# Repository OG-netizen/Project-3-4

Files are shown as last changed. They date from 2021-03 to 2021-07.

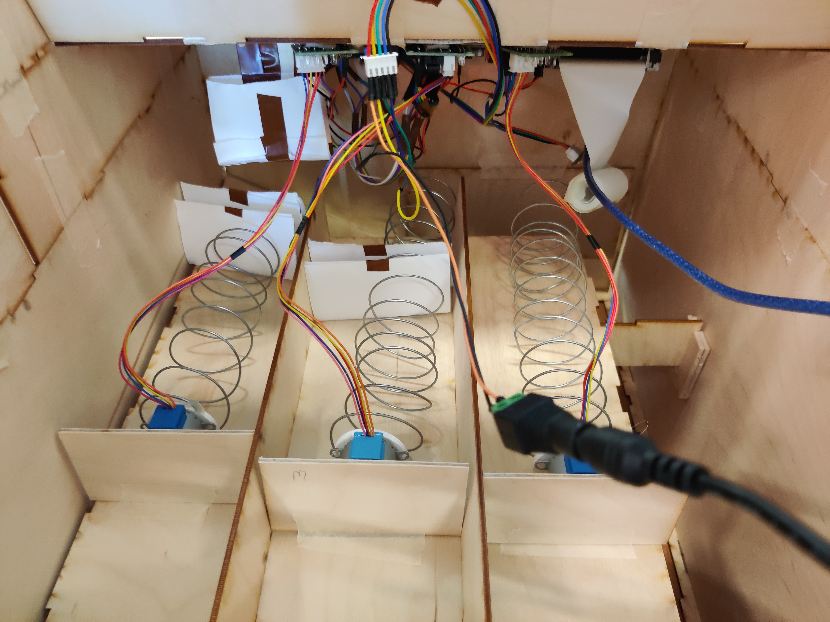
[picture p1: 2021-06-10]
Documenten/Atm binnenkant.jpg

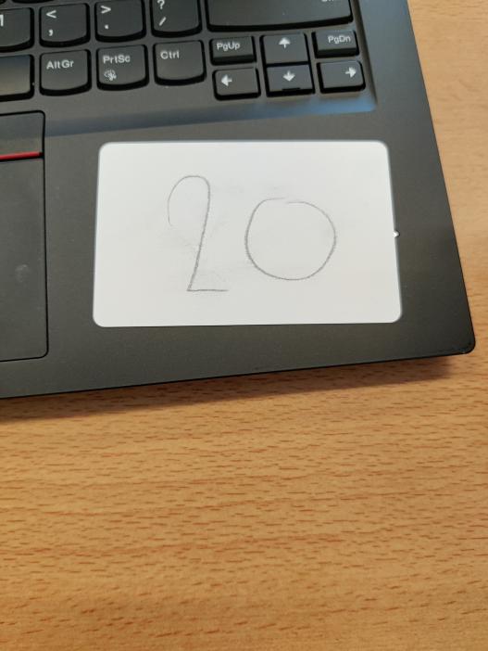
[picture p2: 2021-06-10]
Documenten/biljet.jpg

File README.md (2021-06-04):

# Project-3/4

Voor dit project moesten we een ATM 🏧 en een banksysteem 💻 bouwen. 



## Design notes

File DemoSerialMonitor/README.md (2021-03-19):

Dit is de serial monitor communicatie tussen java en arduino.

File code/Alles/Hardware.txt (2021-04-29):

3 Motoren 	|| 4*3 = 12 pins || 1*3 = 3 5v || 1*3 = 3 gnd
1 Bonprinter 	|| 3 pins || 1 gnd ||stekker 
1 RFID 		|| 5 pins || 1 3v || 1 gnd
1 Keypad	|| 8 pins
8 Buttons	||

totaal 		|| 28 pins || 1 3v || 3 5v || 5 gnd || 1 stekker

Pins used:
Motoren: 12
23, 25, 26, 27, 28, 29, 30, 32, 34, 36, 38, 40

Bonprinter: 2
37, 39

Keypad: 8
42, 43, 44, 45, 46, 47, 48, 49

RFID: 5
5, 50, 51, 52, 53

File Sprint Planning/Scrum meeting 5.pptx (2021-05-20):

## PO Meeting

## Sprint review

- Land voor onze landserver
- Flowchart aangepast
- Sketch gemaakt voor lasercutting

## Nieuwe flowchart

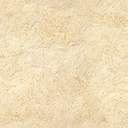
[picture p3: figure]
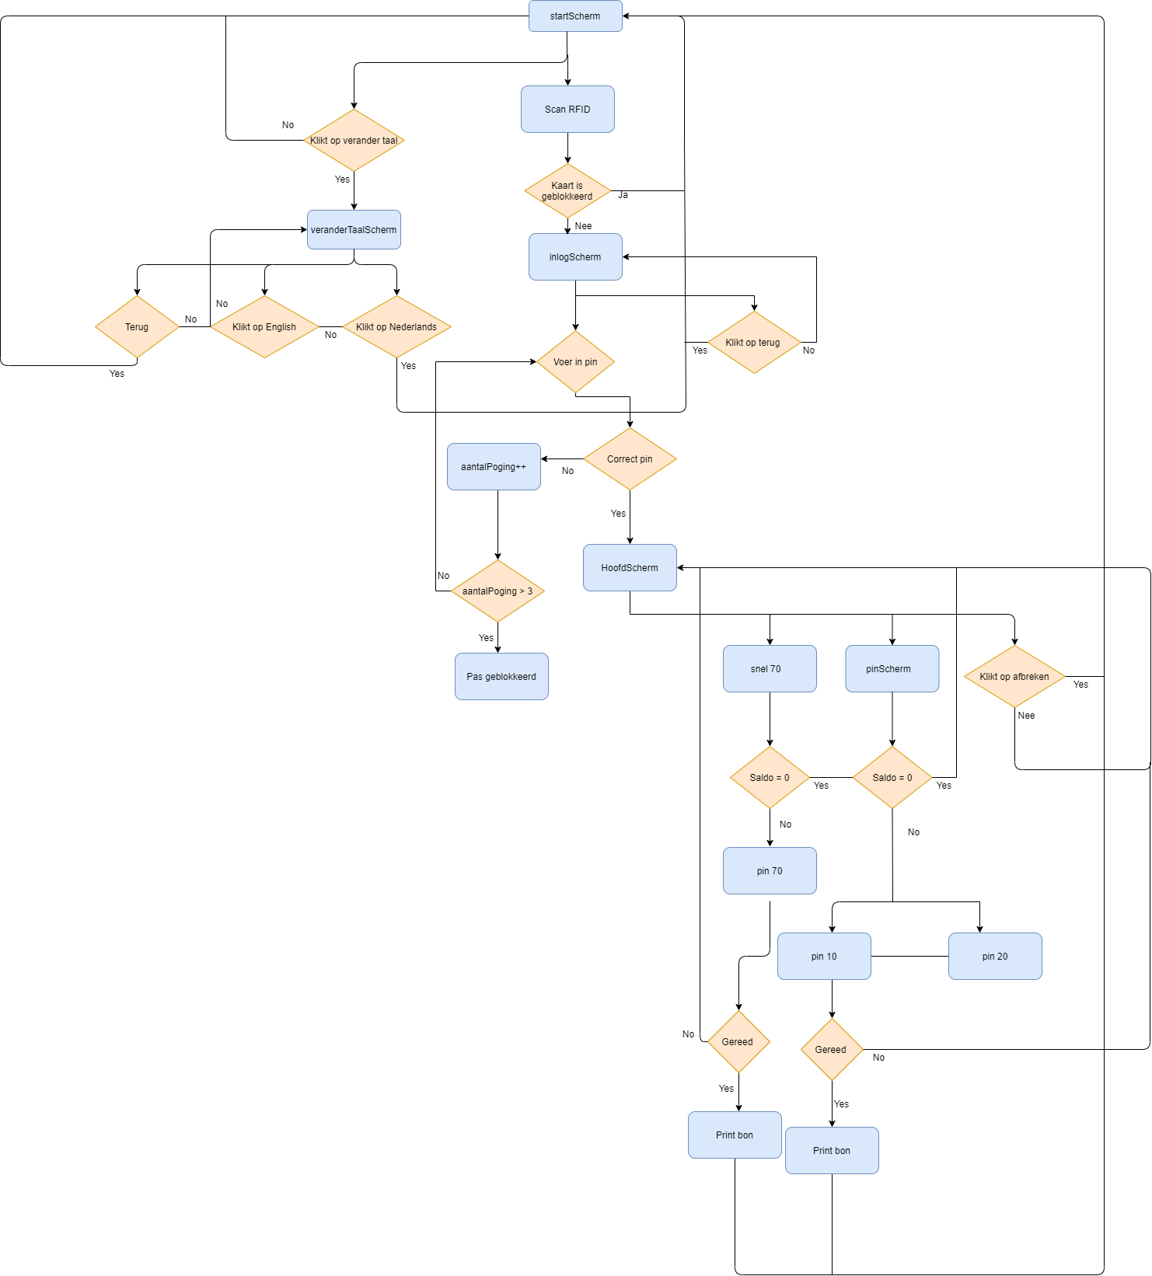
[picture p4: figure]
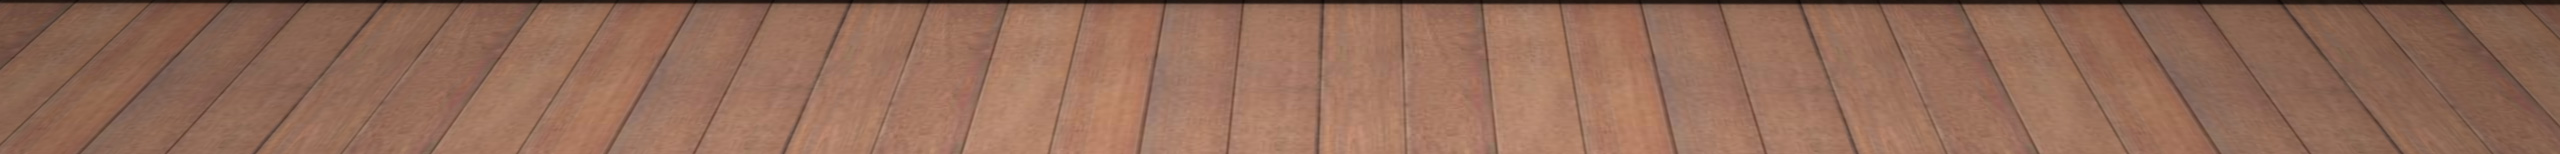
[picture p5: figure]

## Land

- Niger
- Country Code : ISO 3166 alpha-2 NE
- IP Adress landserver: 145.24.222.250
- Iban : NI42 FATM 8765 4321
- Port 22

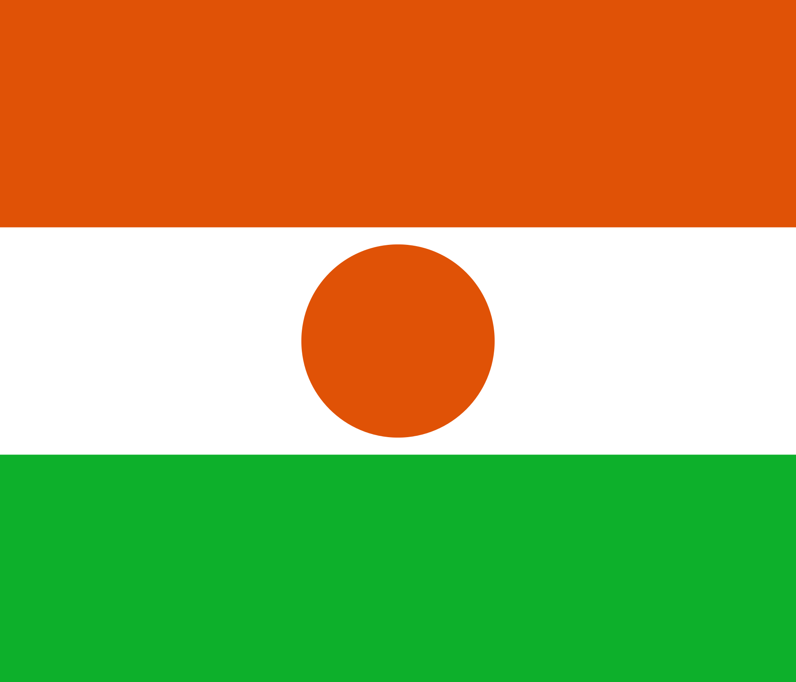
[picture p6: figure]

## Lasercutting sketch

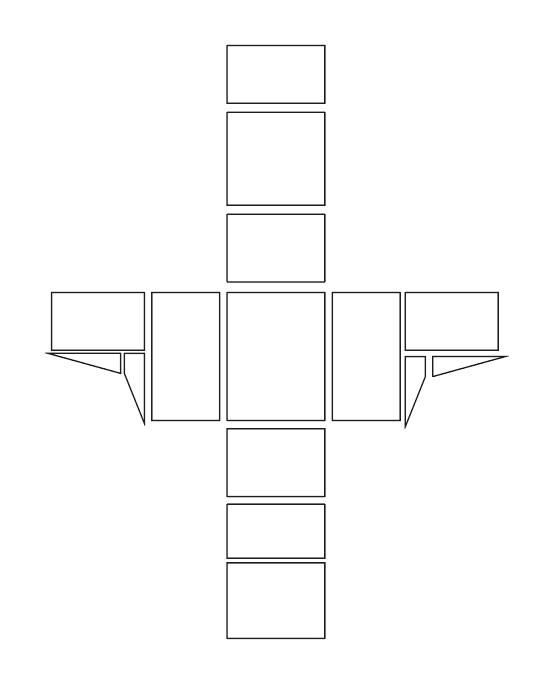
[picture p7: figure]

## demonstratie

- Inloggen
- Pinnen
- Stepper motoren
- Bon printer

## OUDE Presentatie Sprint Backlog

Features | Wil ik | Als gebruiker | Waarom | Taken | Moeilijkheids-graad | Acceptance criteria
7 | Prototype maken van de ATM | De werknemer | Zodat de werknemer alle hardware componenten kunnen testen | Ontwerp bovenkant lasersnijden met afmetingen | 10 | Ontwerp bovenkant moet gaten bevatten voor 8 knoppen, Pin ingang, Bon uitgang, numpad, Laptop scherm stand.
| | | | Ontwerp onderkant laser cutten met afmetingen | | Ontwerp onderkant moet gaten bevatten voor de biljetten dispenser.
| | | | Dispenser ontwerp laser cutten met afmetingen | | Dispenser moet 3 dispenser bakken bevatten om de biljetten uit te werpen.

## nieuwe Presentatie Sprint Backlog

Features | Wil ik | Als gebruiker | Waarom | Taken | Moeilijkheids-graad | Acceptance criteria
8 | Pinnen in elke landen | De klanten | Het zou fijn zijn als klanten kan pinnen in andere landen. Dan weet de klant dat hij/zij met rust kan geld opnemen in andere landen. | Programmeren van een REST API voor het interactie met de landserver | 7 | Ontwerp bovenkant moet gaten bevatten voor 8 knoppen, Pin ingang, Bon uitgang, numpad, Laptop scherm stand.
| | | | Setup onze landserver | 6 | Ontwerp onderkant moet gaten bevatten voor de biljetten dispenser.
| | | | Landserver kan communiceren met de NOOB server | 7 | Dispenser moet 3 dispenser bakken bevatten om de biljetten uit te werpen.

## Retrospective

  - Wat kan er beter?

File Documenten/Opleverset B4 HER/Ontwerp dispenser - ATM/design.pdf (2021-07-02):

390 mm

510 mm

Grootte ribbels en dikte plank is 3mm | Dispenser

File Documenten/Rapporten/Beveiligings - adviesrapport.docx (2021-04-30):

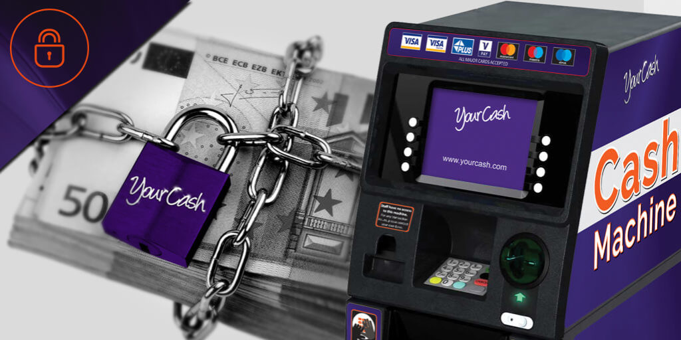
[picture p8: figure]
Beveilig je geldautomaat, beveilig je klanten

Beveiligings- adviesrapport Project 3/4 | Namen - Bryan Chung (0990458) - Jia-jie Yeh (0992427) - Jurgen van den Berg (1000875) - Wouter van Huut (1018984) Groep :B4 / Klas :TI1B Inleverdatum 30-04-2021 Versie 1

# Hst 1. Beveiliging rapport

## 1.1 Data Flow Diagram (DFD)

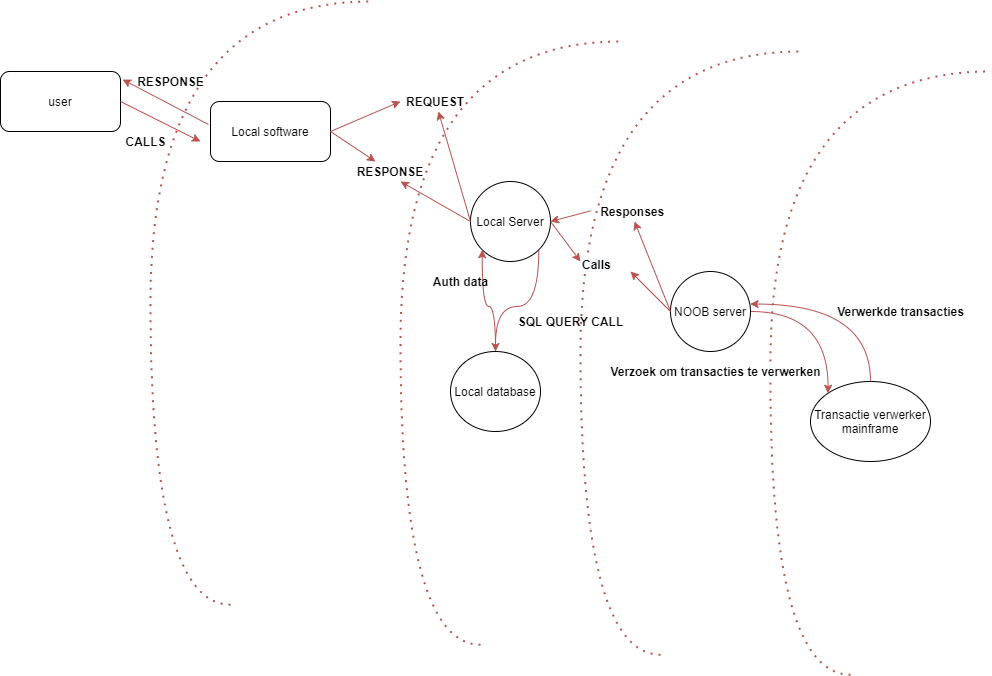
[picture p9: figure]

## 1.2 Risicoanalyse

| Soorten risico aanvallen | Uitvoering
1 | Rogue keyboard access | Dit is een fysiek toetsenbord koppelen aan een pinautomaat en vervolgens een stukje code of een SQL – injectie executeren. De aanvaller kan de pinautomaat dan controleren.
2 | Skimming | Met deze methode dupliceer je de gegevens van een pinpas. Dit gebeurd door een replica te maken van een pinautomaat en dat plaatsen ze aanvallers op het pin sectie.
3 | Keylogging | Dit is het zelfde geval van skimming, maar dan voor de gebruiker zijn pincode. Er wordt dan een replica keypad over het standaard pin keypad gelegd, waardoor de gebruiker zijn pincode wordt gestolen.
4 | Dataverbinding | Als er iemand tussen de dataverbinding van het systeem komt, dan is het systeem is niet versleuteld. Hierdoor zijn de onderdelen bijvoorbeeld; de informatie van de keypad en de gui zeer gevoelig.
5 | SQL | De gui moet beveiligd worden voor aanvallen, zoals SQL-injectie. Hierdoor krijgt de aanvaller gebruik tot je data in je database. Dit kan vernietigd of gestolen worden.
6 | Brute force | De aanvaller kan ook via brute force aanvallen op meerdere onderdelen van het systeem. Hierbij kunnen de data zoals; pincodes en wachtwoorden van de gebruiker te verkrijgen.

## 1.3 Maatregelen

| Soorten risico aanvallen | Oplossingen
1 | Rogue keyboard access | Dit is een van de makkelijkste aanvalssoort op de ATM, waardoor het ook gelijk makkelijk te detecteren is. Hierdoor kan je als een nieuw apparaat wordt toegevoegd dan wordt het ATM stop gezet. Je kan ook speciale karakters accepteren.
2 | Skimming | Dit kan je oplossen om door een elektromagnetische puls. Dit geeft een korte schok aan de skimmer. De schok verstoort of beschadigd de skimmer.
3 | Keylogging | De aanvaller is moeilijk te detecteren, want tegenwoordig niet altijd een keypad replica gebruikt, maar ook een USB-stick. Eerst was de oplossing voelen aan de toetsenbord en kijken of het nep is. Dit is het zelfde geval bij het gebruik van de rogue keyboard.
4 | Dataverbinding | Dit valt op te lossen om beveiliging te maken door middel van SHA-3^15 hash of encryptie. Hierdoor krijgt de aanvaller onleesbare data.
5 | SQL | Deze aanval kan je voorkomen om de input validatie te gebruiken.
6 | Brute force | Om het systeem te beschermen tegen DDoS aanvallen van de aanvaller kan je bijvoorbeeld een Anti DDoS systeem gebruiken. In Nederland is een bekende zogenaamd NaWas. Er is ook een Nationale Anti-DDoS coalitie.

## 1.4 Attack tree

Om een helder beeld te krijgen van een beveiligingssysteem wordt er een attack tree gemaakt. Deze attack tree geeft een beeld over de situaties van de risico aanvallen op het systeem en hoe het systeem op reageert.

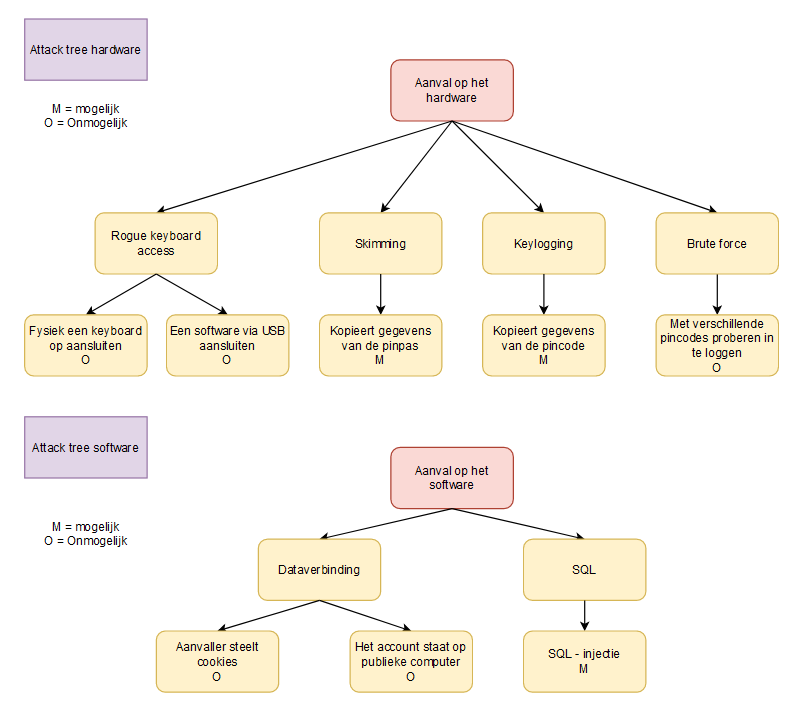
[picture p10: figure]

## Literatuurlijst

# Beveiligingsbronnen

1. https://www.kaspersky.com/blog/atm-attacks-2/15160/

https://jarnobaselier.nl/rogue-access-point-easy-wifi-hacking/

2. https://www.lookingglasscyber.com/blog/atm-hacking-you-dont-have-to-pay-to-play/

https://www.tpsworldwide.com/atm-skimming-preventing-bank-card-hacks/

https://mens-en-samenleving.infonu.nl/diversen/22626-hoe-skimmers-skimmen.html

3. https://www.pandasecurity.com/en/mediacenter/security/keyloggers-be-careful-what-you-type/

https://ecobank.com/personal-banking/security-centre/scams/keyloggers

https://www.malwarebytes.com/keylogger/

4. https://www.vpngids.nl/veilig-internet/surfen/wat-is-encryptie/
5. https://kinsta.com/nl/blog/sql-injecties/

https://cheatsheetseries.owasp.org/cheatsheets/SQL_Injection_Prevention_Cheat_Sheet.html

6. https://www.ncsc.nl/onderwerpen/ddos/het-nederlandse-anti-ddos-initiatief

https://www.nbip.nl/nawas/

# Hst 2. Advies rapport

## 2.1 onderzoeksvragen

- Is het ontwerp compleet, of mist het nog informatie?

Nee, het mist geen informatie en ziet er compleet uit. Het bevat alle standpunten en bij de literatuurlijst zijn alle belangrijke bronnen vermeld en door een website link verbonden.

- Kan er iets kapot gaan en verbeterd worden?

Ja, de dispenser uitgang kan ingebroken worden. Maar door een verbetering is het bedekt met een plaat, waardoor de aanvaller niet meer in kan komen.

- Zie je nog blinden vlekken die de peergroep gemist heeft?

Nee, we konden geen open plekken vinden. Waarbij aanvallen mogelijk zijn op de pinautomaat.

- Zijn de maatregelingen sterk genoeg?

Ja, de maatregelingen bedekken grotendeels de belangrijke zwakke punten van de bank. Zelfs heeft de peercoach groep meer dan 1 maatregelingen kunnen vinden voor 1 risico.

- Zijn de informatiebronnen uitgebreid genoeg?

De literatuurlijst is goed uitgebreid en verwerkt de standpunten van de bronnen die gebruikt zijn. Dit geeft een goed zicht waar het informatie vandaan komt.

- Ziet de attack tree van de peergroep goed uit?

De attack tree van de peergroep is ook in 2 delen verdeeld. In een hardware -en software gedeelte. Het hardware gedeelte is verdeeld hoe het fysiek ingebroken wordt, hoe moeilijk de hardware componenten betast worden en hoe de bank bescherming van de gelddispenser. Het software gedeelte is verdeeld in database hacken, datastroom onderscheppen, de GUI en pinpas stelen. Hier worden de moeilijkheidsgraden van de aanvallen gemankeerd met een ‘P van possible’ en ‘I van impossible’. Dit zorgt ervoor een gedetailleerde overzicht over de aanvallen op de bank.

- Is de DFD compleet?

Alle standpunten van de bank zijn er in verwerkt. De gebruiker heeft dan een laag voor het invoeren van zijn data dus de pincode, balans en card ID. Dit wordt dan verstuurd naar de volgende laag en dat is de ATM laag. Hier wordt de data van de gebruiker verstuurd naar de landelijke server. Dit wordt dan vergeleken met de banken die er allemaal verbonden zijn aan de landelijke server via een Iban id. Anders gaat het via de Noob server als het uit een andere land komt. Hier wordt dan de data terug gestuurd.

## 2.2 beveiligingsadvies

In het geheel is het beveiligingsrapport goed bedekt. De zwakke punten waar de bank overvallen kan worden zijn goed bedekt met maatregelen die het aanval proef maakt. Voor de rest ziet het er goed uit. De feedback zal ervoor zorgen dat de beveiligingsrapport verbeterd wordt. De bronnen zijn duidelijk met goeie standpunten ernaast en de attack tree/DFD geven een goed geheel over het ontwerp.

## 2.3 Advies landbank

- De communicatie tussen de banken wordt gedaan door een landelijke server op te zetten. Alle banken met de zelfde land verbinden hier dan aan. Als een persoon met een bankpas wilt gaan pinnen van een bank in het zelfde land dan is dit mogelijk.

Als de comminactieprotocol wordt er met een GET en POST request gewerkt. Deze request zijn dan onderdeel van een communicatie via HTTP verbinding. Hiermee wordt het veiliger gemaakt en gebruikt gemaakt van SSL. Dit protocol wordt dan HTTPS.

Dus wat ons peergroep down is een landelijke communicatie op te stellen en helpen opstellen met andere peergroepen. Hiermee worden de beveiliging van de verbinding tussen de pinautomaten, landelijke server en databases gemaakt. Door het besluit van de communicatie tussen banken in ons land hebben we een het onderwerp gelijk verdeeld met elkaar. Iedereen heeft dan evenveel te doen.

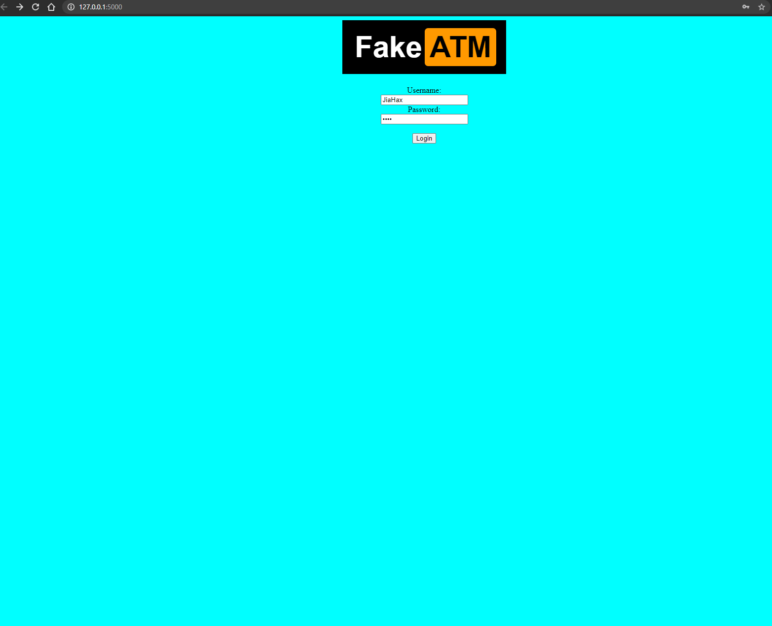
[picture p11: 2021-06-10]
Documenten/design.png

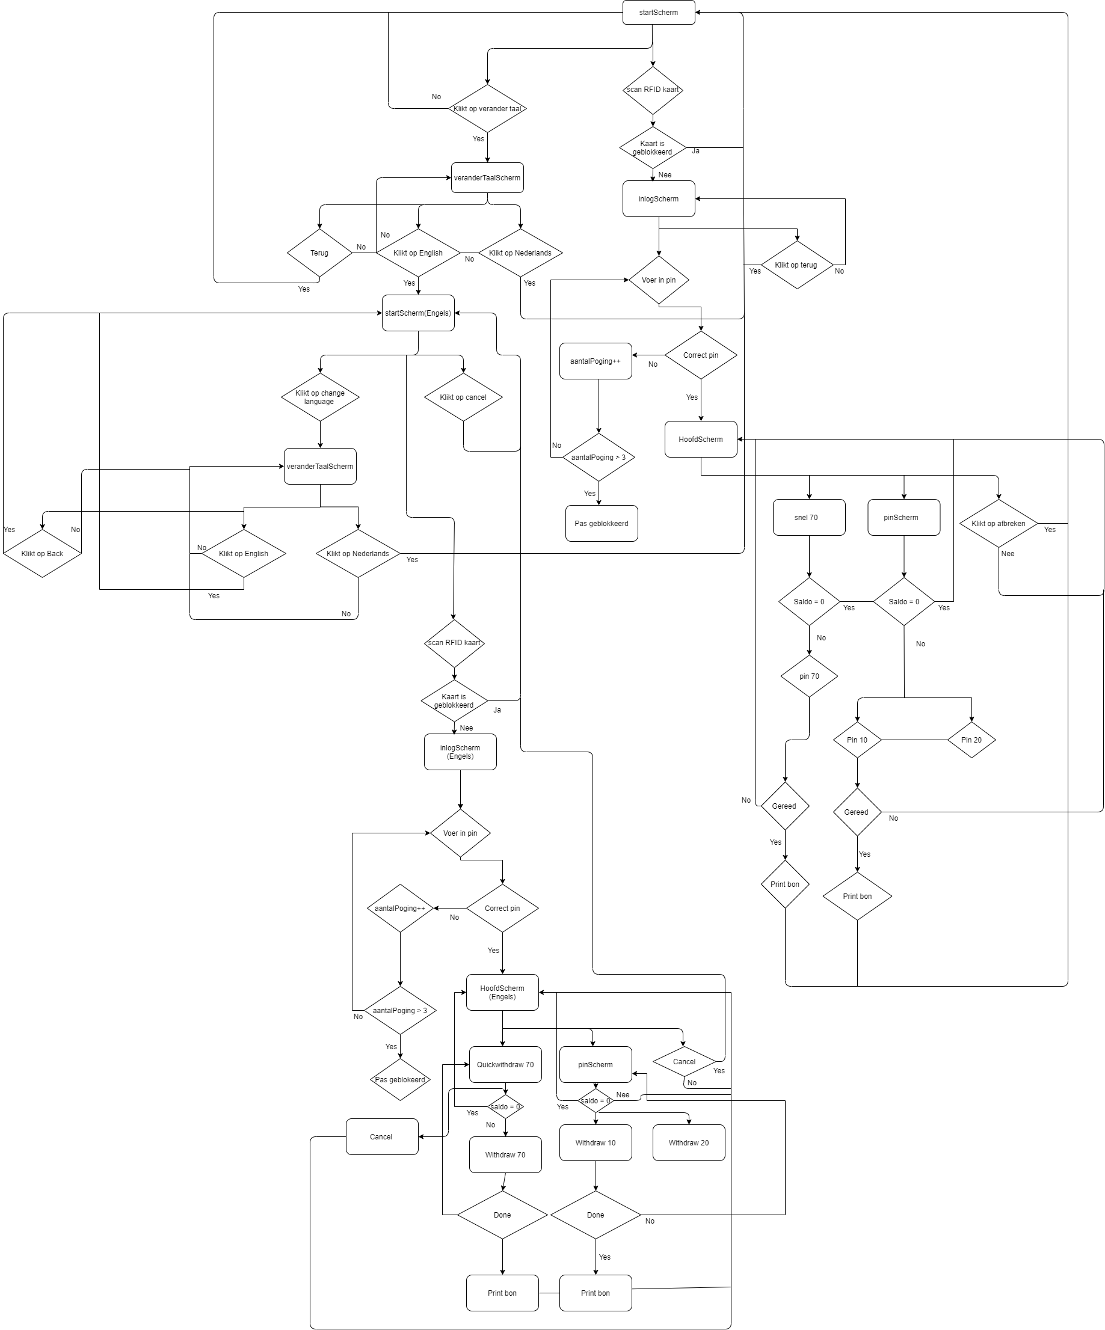
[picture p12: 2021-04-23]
Documenten/TweedeIteratieFlowChartGUI.png

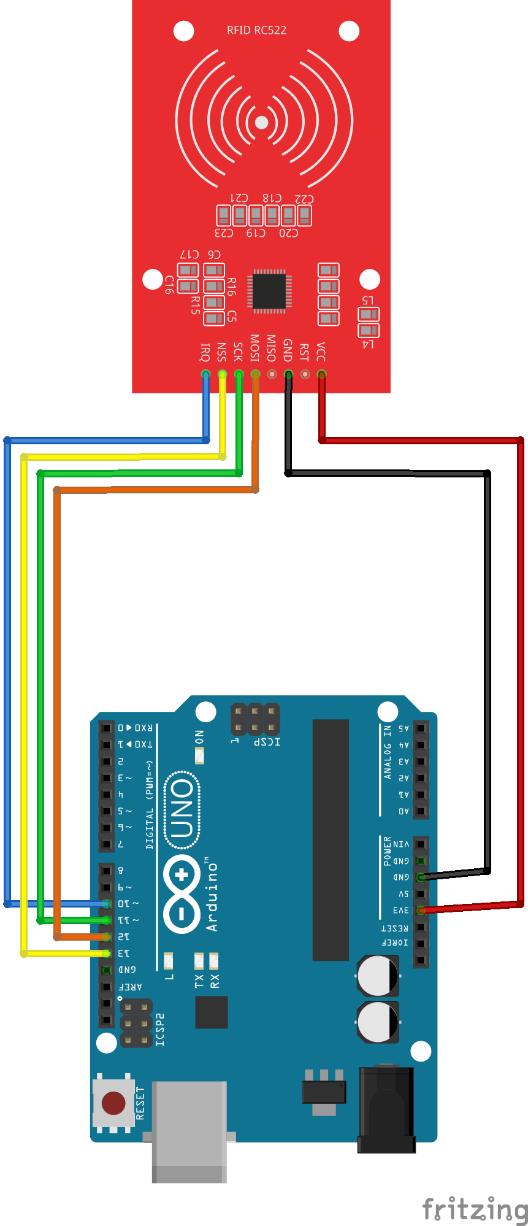
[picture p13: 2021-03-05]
code/Alles/Losse onderdelen/RFID/RFID_bb.png

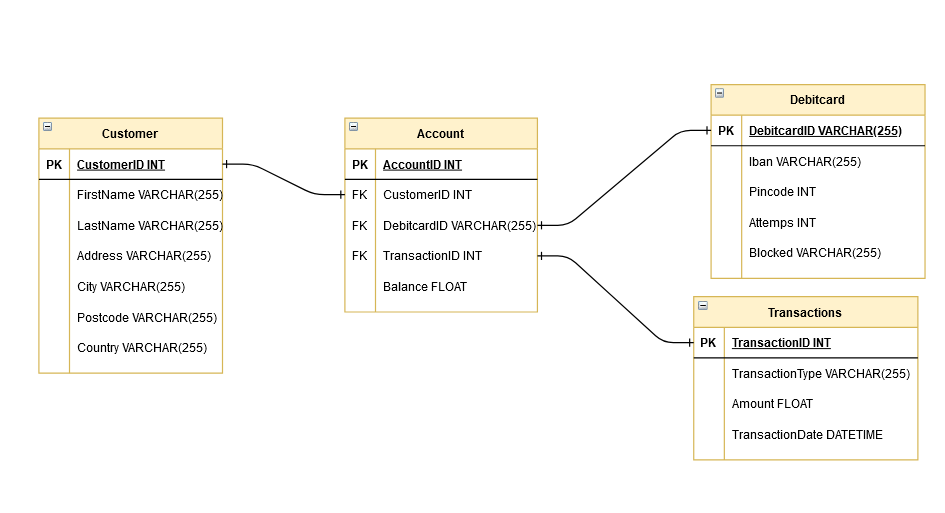
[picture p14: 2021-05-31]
Documenten/Database ontwerp/database ontwerp 4.png

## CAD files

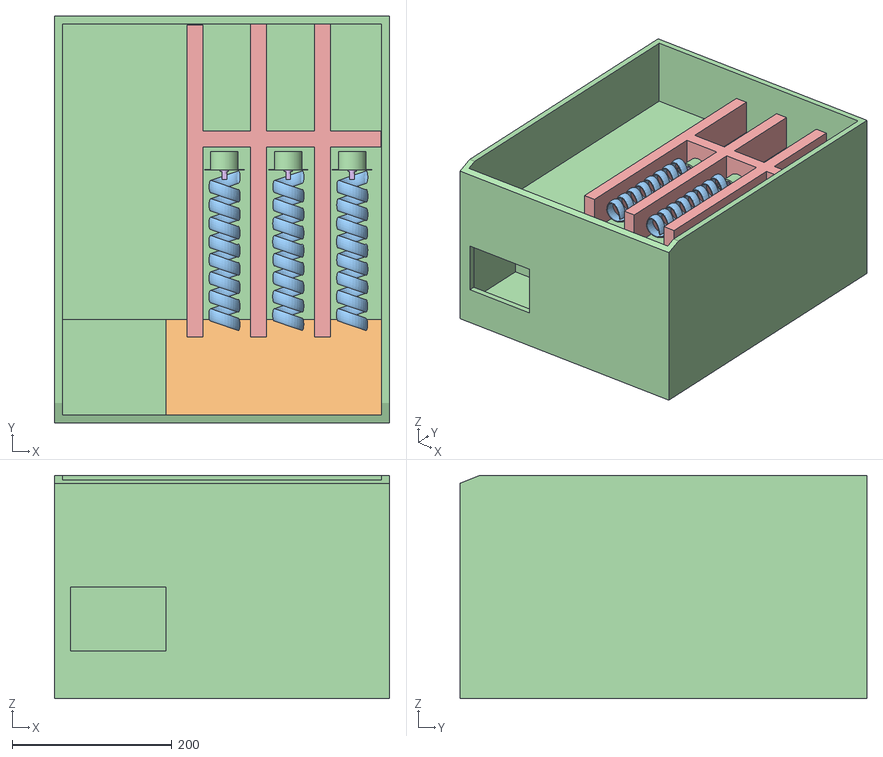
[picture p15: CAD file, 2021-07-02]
Documenten/Opleverset B4 HER/Ontwerp dispenser - ATM/FakeATM-dispenser.obj
420.0 x 510.0 x 280.0

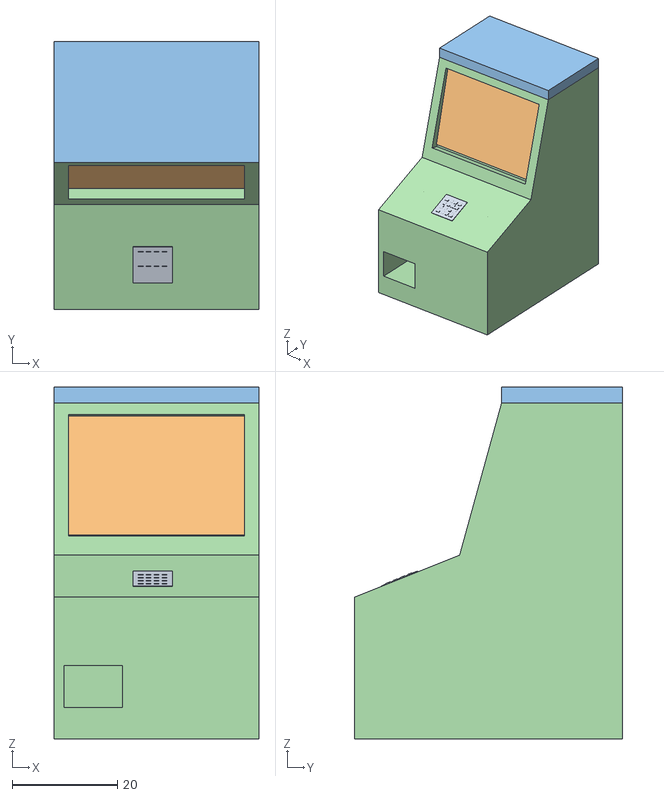
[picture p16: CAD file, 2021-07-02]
Documenten/Opleverset B4 HER/Ontwerp dispenser - ATM/FakeATM.obj
39.0 x 51.0 x 67.0

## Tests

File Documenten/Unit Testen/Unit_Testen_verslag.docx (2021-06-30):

Unit testen

Project 3/4

Groep: Bryan Chung (0990458), Jia-Jie-Yeh (0992427), Jurgen van den Berg (1000875),Wouter van Huut (1018984)

API

Eerste test

Test: Gaat de API de juiste response geven wanneer ze requests krijgt van de landserver. We willen ook weten bij edge case (extreem probleem) of het werkt.

Criteria:

De api moet kunnen de juiste response geven bij verschillende omstandigheden. Bij een edge case moet onze api door moeten draaien. Als er 0 failure is bij onze unit test dan slaag onze test.

Testopstelling:

Er is een Java-bestand in onze Ubuntu server die de API requests behandelen. Met behulp van unit testen kunnen we verschillende features bij verschillend omstandigheden testen. En we kunnen zien hoeveel errors er oplevert bij onze test. Bij een edge case hebben we manually een groot hoeveelheid requests gestuurd naar onze api.

Testprocedure:

- Run het UnitTestAPI.java in het Ubuntu server
- Kijk of er failures bij de console bestaat

Test resultaat:

Onze API stuurt de juiste response bij alle omstandigheden. Bij een edge case draait onze API niet door er bestaat een overload aan de maximum client. Bij de unit test levert er 7 failures bij maximum aantal reuqest (edge case).

Test geslaagd:

Test is geslaagd alleen als er geen edge case scenario was dus test niet geslaagd.

Tweede test

Test: Gaat de API de juiste response geven wanneer ze requests krijgt van de landserver. We willen ook weten bij edge case (extreem probleem) of het werkt.

Criteria:

De api moet kunnen de juiste response geven bij verschillende omstandigheden. Bij een edge case moet onze api door moeten draaien. Als er 0 failure is bij onze unit test dan slaag onze test.

Testopstelling:

Er is een Java-bestand in onze Ubuntu server die de API requests behandelen. Met behulp van unit testen kunnen we verschillende features bij verschillend omstandigheden testen. En we kunnen zien hoeveel errors er oplevert bij onze test. Bij een edge case hebben we manually een groot hoeveelheid requests gestuurd naar onze api.

Testprocedure:

- Run het UnitTestAPI.java in het Ubuntu server
- Kijk of er failures bij de console bestaat

Test resultaat:

Onze API stuurt de juiste response bij alle omstandigheden. Bij een edge case draait onze API niet door er bestaat een overload aan de maximum client. Bij de unit test levert er nu 2 failures bij maximumaantal requests (edge case).

Test geslaagd:

Test is niet geslaagd API stopt bij een edge case scenario.

Derde test

Test: Gaat de API de juiste response geven wanneer ze requests krijgt van de landserver. We willen ook weten bij edge case (extreem probleem) of het werkt.

Criteria:

De api moet kunnen de juiste response geven bij verschillende omstandigheden. Bij een edge case moet onze api door moeten draaien. Als er 0 failure is bij onze unit test dan slaag onze test.

Testopstelling:

Er is een Java-bestand in onze Ubuntu server die de API requests behandelen. Met behulp van unit testen kunnen we verschillende features bij verschillend omstandigheden testen. En we kunnen zien hoeveel errors er oplevert bij onze test. Bij een edge case hebben we manually een groot hoeveelheid requests gestuurd naar onze api.

Testprocedure:

- Run het UnitTestAPI.java in het Ubuntu server
- Kijk of er failures bij de console bestaat

Test resultaat:

Onze API stuurt de juiste response bij alle omstandigheden. Bij een edge case draait onze API door er bestaat een overload aan de maximum client. Bij de unit test levert er 0 failures bij maximumaantal requests (edge case), De API drooit gewoon door.

Test geslaagd:

Test is geslaagd.

Dispenser

Eerste test

Test: Kan de dispenser de gevraagde hoeveelheid biljetten uitgeven?

Criteria:

De test is geslaagd wanneer de dispenser de correcte hoeveelheid biljetten uitgeeft bij de gevraagde hoeveelheid biljetten.

Testopstelling:

Dispenser aangedreven door 9V batterij via een driver. De dispenser werd bestuurd door een Arduino mega via de serial port.

Testprocedure:

- Sluit de dispenser motor met de driver en die driver sluit die aan met de arduino mega.
- Op testprogramma kun je een hoeveelheid biljet vragen aan de motordispenser
- De dispenser zou nu de biljetten uitgeven

Testresultaat:

De dispenser geeft de correcte hoeveelheid biljetten. De dispenser geeft van groot naar de klein de correcte biljetten.

Test geslaagd:

Ja de test is geslaagd.

RFID-lezer

Eerste test

Test: Kan de RFID lezer de kaart uitlezen en de correct data doorgeven aan de arduino mega?

Criteria:

Als de RFID-lezer de kaart leest en de correcte data stuurt naar de serial port dan is de test geslaagd.

Testopstelling:

RFID-lezer is aangesloten aan de arduino mega en die arduino mega is aangesloten aan de computer via serial port.

Testprocedure:

- Run het test programma
- Hou een kaart voor de RFID-lezer
- Lees de data uit de serial monitor

Testresultaat:

De RFID-lezer leest de kaart en stuurt de correcte data.

Test geslaagd:

Ja de test is geslaagd.

Bonprinter

Eerste test

Test:

Kan de bonprinter via serial port van de computer printen?

Criteria:

De test is geslaagd als de bonprinter kan gegevens van de serial port bewerken en die printen.

Testopstelling:

Sluit de thermal printer aan de arduino. Sluit die arduino op de computer via serial port.

Testprocedure:

- Zorg ervoor dat alles goed aangesloten is
- Open het test programma en run het.
- De printer zou de data bewerken en printen
- Als de printer klaar is met printen dan stopt die helemaal
- Pak die bon en lees het

Testresultaat:

De printer print wel de bon, maar er werd een verkeerde bon geprint.

Test geslaagd:

Test is niet geslaagd, de correcte data wordt niet geprint.

Tweede test

Test:

Kan de bonprinter via serial port van de computer printen?

Criteria:

De test is geslaagd als de bonprinter kan gegevens van de serial port bewerken en die printen.

Testopstelling:

Sluit de thermal printer aan de arduino. Sluit die arduino op de computer via serial port.

Testprocedure:

- Zorg ervoor dat alles goed aangesloten is
- Open het test programma en run het.
- De printer zou de data bewerken en printen
- Als de printer klaar is met printen dan stopt die helemaal
- Pak die bon en lees het

Testresultaat:

De printer print de correcte bon het print exact wat het programma stuurt.

Test geslaagd:

Test is geslaagd, de correcte bon wordt geprint.

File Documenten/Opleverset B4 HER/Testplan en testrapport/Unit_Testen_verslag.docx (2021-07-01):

# Unit testen en Integratie

Project 3/4

Groep: Bryan Chung(0990458), Jia-Jie-Yeh(0992427),Jurgen van den Berg(1000875),Wouter van Huut(1018984)

# API

Test poging: | Eerste keer.
Unit test: | Gaat de API de juiste response geven wanneer ze requests krijgt van de landserver. We willen ook weten bij edge case (extreem probleem) of het werkt.
Criteria | De api moet kunnen de juiste response geven bij verschillende omstandigheden. Bij een edge case moet onze api door moeten draaien. Als er 0 failure is bij onze unit test dan slaag onze test.
Test opstelling: | Er is een Java bestand in onze Ubuntu server die de API requests behandelen. Met behulp van unit testen kunnen we verschillende features bij verschillend omstandigheden testen. En we kunnen zien hoeveel error er oplevert bij onze test. Bij een edge case hebben we manual een groot hoeveelheid requests gestuurd naar onze api.
Test procedure: | - Run het UnitTestAPI.java in het ubuntu server - Kijk of er failure bij de console bestaat
Edge case: | Stuur 100 request naar de API.
Test resultaat: | Onze API stuurt de juiste response bij alle omstandigheden behalve een edge case. Bij een edge case draait onze API niet door.
Test geslaagd: | Test is geslaagd alleen als er geen edge case scenario was dus test niet geslaagd.

Test poging: | Tweede keer.
Unit test: | Gaat de API de juiste response geven wanneer ze requests krijgt van de landserver. We willen ook weten bij edge case (extreem probleem) of het werkt.
Criteria | De api moet kunnen de juiste response geven bij verschillende omstandigheden. Bij een edge case moet onze api door moeten draaien. Als er 0 failure is bij onze unit test dan slaag onze test.
Test opstelling: | Er is een Java-bestand in onze Ubuntu server die de API requests behandelen. Met behulp van unit testen kunnen we verschillende features bij verschillend omstandigheden testen. En we kunnen zien hoeveel error er oplevert bij onze test. Bij een edge case hebben we manual een groot hoeveelheid requests gestuurd naar onze api.
Test procedure: | - Run het UnitTestAPI.java in het Ubuntu server - Kijk of er failure bij de console bestaat
Edge case: | Stuur 100 request naar de API.
Test resultaat: | Onze API stuurt de juiste response bij alle omstandigheden. Bij een edge case draait onze API niet door er bestaat een overload aan de maximum client. Bij de unit test levert er nu 2 failures bij maximumaantal requests (edge case).
Test geslaagd: | Test is niet geslaagd API stopt bij een edge case scenario.

Test poging: | Derde keer.
Unit test: | Gaat de API de juiste response geven wanneer ze requests krijgt van de landserver. We willen ook weten bij edge case (extreem probleem) of het werkt.
Criteria | De api moet kunnen de juiste response geven bij verschillende omstandigheden. Bij een edge case moet onze api door moeten draaien. Als er 0 failure is bij onze unit test dan slaag onze test.
Test opstelling: | Er is een Java bestand in onze Ubuntu server die de API requests behandelen. Met behulp van unit testen kunnen we verschillende features bij verschillend omstandigheden testen. En we kunnen zien hoeveel error er oplevert bij onze test. Bij een edge case hebben we manual een groot hoeveelheid requests gestuurd naar onze api.
Test procedure: | - Run het UnitTestAPI.java in het Ubuntu server - Kijk of er failure bij de console bestaat
Edge case: | Stuur 100 request naar de API.
Test resultaat: | Onze API stuurt de juiste response bij alle omstandigheden. Bij een edge case draait onze API door er bestaat een overload aan de maximum client. Bij de unit test levert er 0 failures bij maximumaantal requests (edge case), De API draait gewoon door.
Test geslaagd: | Test is geslaagd.

# Bon printer

Test poging: | Eerste keer.
Unit test: | Kan de bon printer via serial port van de computer printen?
Criteria | De test is geslaagd als de bon printer kan gegevens van de serial port bewerken en die printen.
Test opstelling: | Sluit de thermal printer aan de arduino. Sluit die arduino op de computer via serial port.
Test procedure: | - Zorg ervoor dat alles goed aangesloten is - Open het test programma en run het. - De printer zou de data bewerken en printen - Als de printer klaar is met printen dan stopt die helemaal - Pak die bon en lees het
Edge case: | Print een foto met een breedte van 384 pixels
Test resultaat: | De printer print wel de bon, maar er werd een verkeerde bon geprint. Bij de edge case kan de thermal printer niet zo goed printen als het foto is 384 pixels breed de kwaliteit van de foto is slecht.
Test geslaagd: | Test is niet geslaagd, de correcte data wordt niet geprint.

Test poging: | Tweede keer.
Unit test: | Kan de bon printer via serial port van de computer printen?
Criteria | De test is geslaagd als de bon printer kan gegevens van de serial port bewerken en die printen.
Test opstelling: | Sluit de thermal printer aan de arduino. Sluit die arduino op de computer via serial port.
Test procedure: | - Zorg ervoor dat alles goed aangesloten is - Open het test programma en run het. - De printer zou de data bewerken en printen - Als de printer klaar is met printen dan stopt die helemaal - Pak die bon en lees het
Edge case | Print een foto met een breedte van 384 pixels
Test resultaat: | De printer print de correcte bon het print exact wat het programma stuurt.
Test geslaagd: | Test is geslaagd, de correcte bon wordt geprint.

# RFID

Test poging: | Eerste keer.
Unit test: | Kan de RFID-lezer de kaart uitlezen en de correct data doorgeven aan de arduino mega?
Criteria | Als de RFID-lezer de kaart leest en de correcte data stuurt naar de serial port dan is de test geslaagd.
Test opstelling: | RFID-lezer is aangesloten aan de arduino mega en die arduino mega is aangesloten aan de computer via serial port.
Test procedure: | - Run het test programma - Hou een kaart voor de RFID-lezer - Lees de data uit de serial monitor
Edge case: | Scan dezelfde kaart heel snel 10 keer achter elkaar
Test resultaat: | De RFID-lezer leest de kaart en stuurt de correcte data. Bij de edge case lukt het niet, het RFID-lezer duurt minstens 2 secondes om die kaart te lezen.
Test geslaagd: | Ja, de test is geslaagd.

# Dispenser

Test poging: | Eerste keer.
Unit test: | Kan de dispenser de gevraagde hoeveelheid biljetten uitgeven?
Criteria | De test is geslaagd wanneer de dispenser de correcte hoeveelheid biljetten uitgeeft bij de gevraagde hoeveelheid biljetten.
Test opstelling: | Dispenser aangedreven door 9V batterij via een driver. De dispenser werd bestuurd door een Arduino mega via de serial port.
Test procedure: | - Sluit de dispenser motor met de driver en die driver sluit die aan met de arduino mega. - Op test programma kun je een hoeveelheid biljet vragen aan de motordispenser. - De dispenser zou nu de biljetten uitgeven.
Edge case: | Geeft een opdracht aan de dispenser om 1 miljoen biljetten te printen
Test resultaat: | De dispenser geeft de correcte hoeveelheid biljetten. De dispenser geeft van groot naar de klein de correcte biljetten. Bij de edge scenario gaat de dispenser blijven printen maar het gaat de 1 miljoen biljetten niet halen. De arduino gaat eventueel stoppen door de geheugenlimit. En de dispenser motoren kan overheaten na zo lange tijd werken.
Test geslaagd: | Ja, de test is geslaagd.

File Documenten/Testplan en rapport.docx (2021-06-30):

# Test plan en -rapport

1. Testen voor de bon printer.

Verwachte resultaat: Dat we de bon printer zonder fouten kunnen gebruiken.

Waarneming: Tijdens het opstellen van de bon printer hebben we via Arduino IDE een voorbeeld code kunnen pakken. We hebben getest met normaal printen en wat de geven waardes waren die we terug kregen. We gingen ook testen hoe we onze merk gingen afbeeldingen. Hiervan zijn dan de waardes aangepast op de variables die wij gebruiken voor het info wat we hadden gebruikt.

Hier is de code van de printer test.[^1]

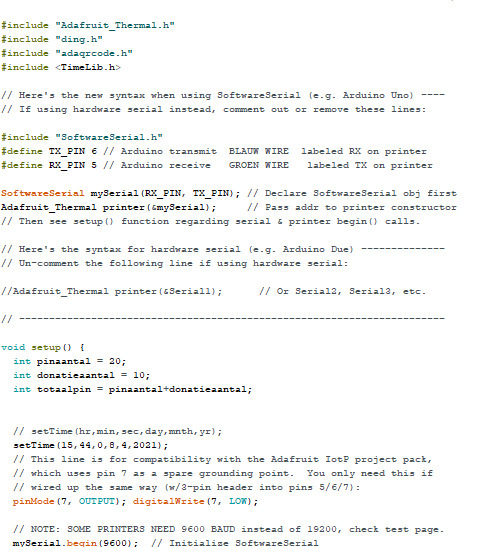
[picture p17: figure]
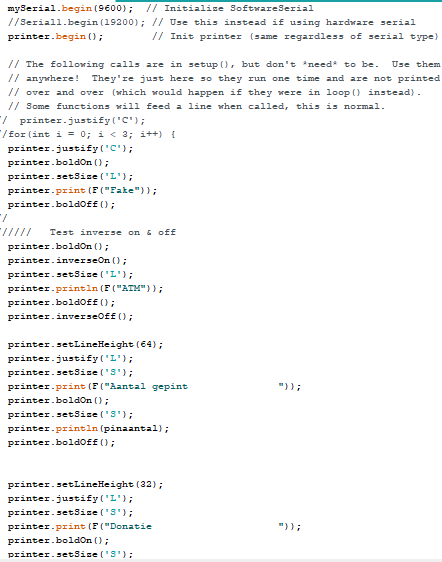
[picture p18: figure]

Dit is oftewel de voorbeeld code van Arduino IDE. Om de rest te kunnen zien moet u naar onze GitHub gaan en dan code > alles > losse onderdelen. Hier staan alle codes.

Conclusie: De test is behaald. We kregen de waardes terug op het bonnetje wat eruit was geprint. Onze logo was ook met een paar aanpassingen duidelijk te zien.

2. Testen op het samenvoeging van alle componenten.

Verwachte resultaat: Dat alle componenten vloeiend met elkaar kan werken.

Waarneming: We zijn vanuit gegaan dat we een Arduino Mega gaan gebruiken als bron. Daarna hebben we 3 dispenser bakken gemaakt, daarvan zijn 3 stappenmotoren in gebruik. De numpad is aangesloten, met de bon printer en de RIFD. Hiervan kregen we eerst data problemen. De data die er werd doorgestuurd via de Mega naar de printer was niet als te soepel. We kregen meestal errores. Dit was opgelost door Wouter en Jurgen die samen aan de componenten aan het testen waren.

We hadden ook problemen met de stappenmotoren gekregen, waardoor de verbinding niet perfect overkwam. Dit was opgelost door een vervanging te bestellen. Dit kwam namelijk door een defecte product.

De code is te groot om te delen via word. Dus we hebben dit in onze GitHub bij code>Alles staan. Hier is een voorbeeld hoe het eruit ziet in de fritzing.

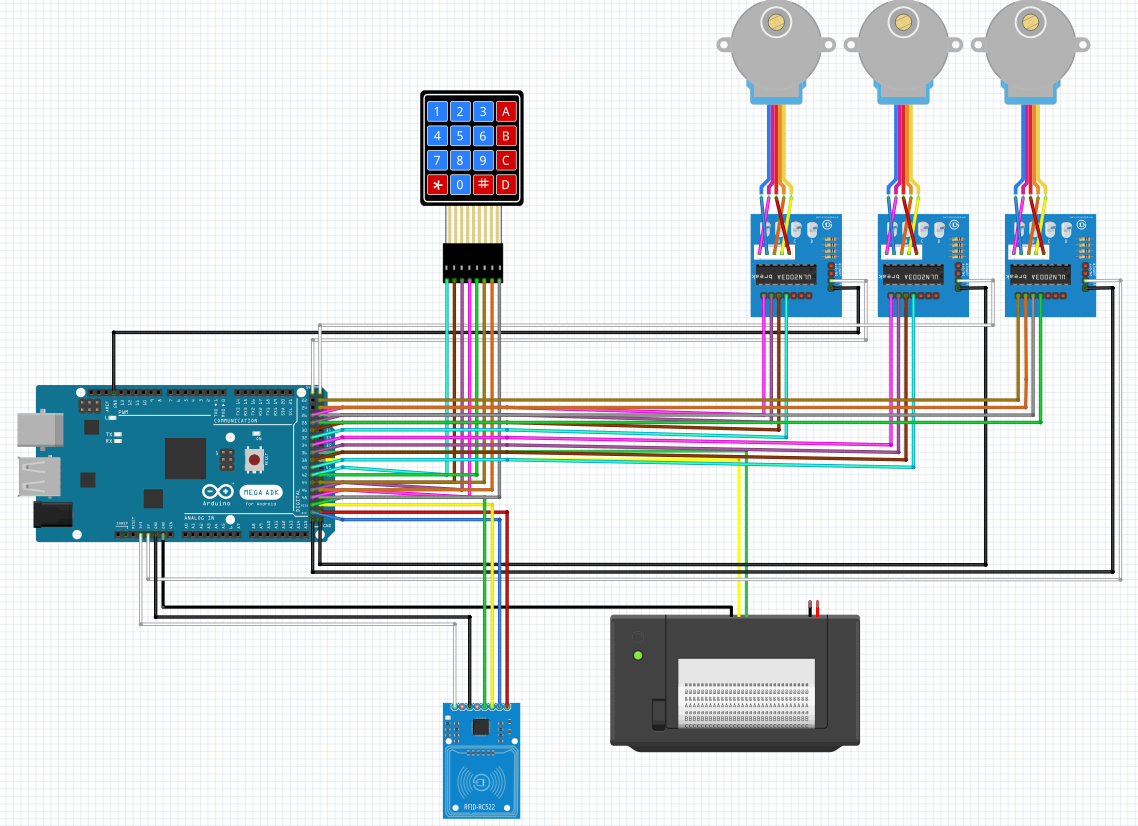
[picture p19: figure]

De numpad en de RIFD hadden geen problemen gemaakt, waardoor we hier niet hoefden te kijken.

Conclusie: De test is behaald. Alle componenten kunnen met elkaar communiceren. De communicatie levert geen problemen op. Hierdoor kunnen we het verbinden met de GUI.

3. Testen voor de gelddispenser.

Verwachte resultaat: Dat 3 soorten biljetten uit onze dispenser kan worden gehaald.

Waarneming: Eerst hadden we een proef ontwerp gemaakt en hoe we het gingen maken.

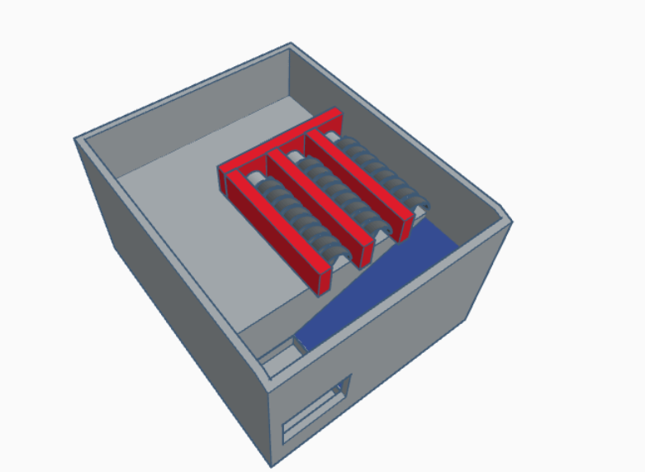
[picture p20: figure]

Als eerst hadden we een snoep automaat in gedachte. Hiervan gingen we vanuit dat biljetten de zelfde manier kunnen gebruiken. Dus we hebben de biljetten afgemeten. We gebruikte hierbij biljetten van 10, 20 en 50 euro. De afmetingen waren 9.9 x 5.1 cm.

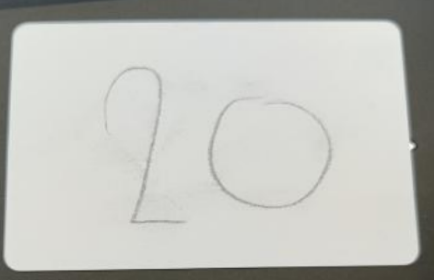
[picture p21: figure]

De 3 geldispensers hebben we in het onderste deel van onze ATM gestopt. Ze bevinden zich naast elkaar.

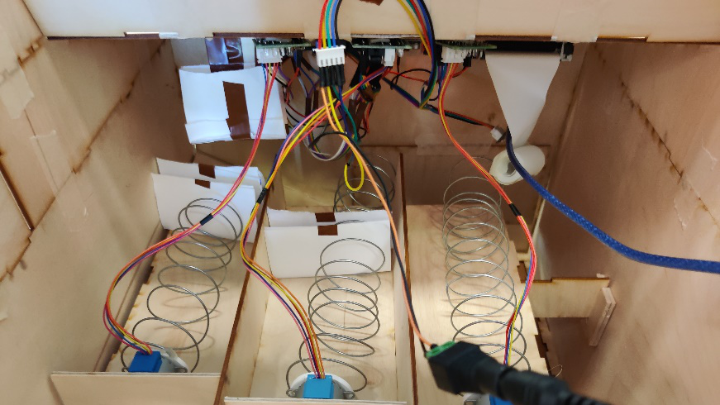
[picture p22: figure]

De biljetten vallen via een schuine baan naar het uitgang van het ATM behuizing.

Tijdens de 6e scrum meeting hadden we een nieuw ontwerp gemaakt voor de dispenser behuizing, want wat er nu boven in de afbeelding wordt weergeven is een prototype.

We zijn dan gaan testen om de biljetten soepel te laten vallen. De biljetten zou dan de schuine baan naar het uitgang toe glijden.

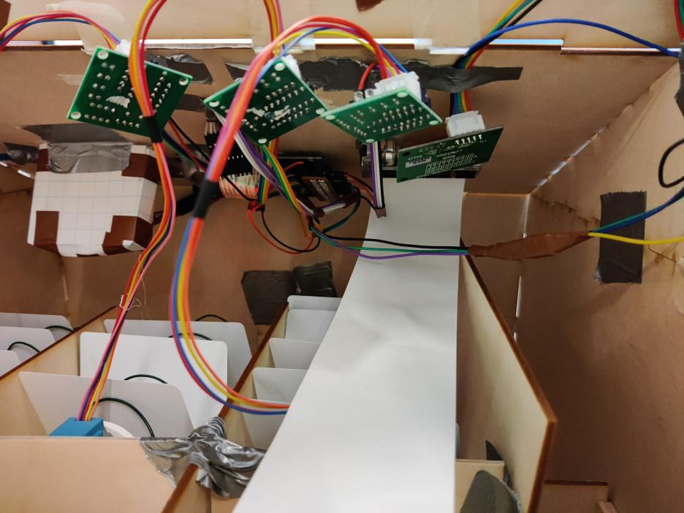
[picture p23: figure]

We hebben hier een nieuw inhoud.

We hebben ook een filmpje in onze GitHub staan, waarvan de werking van de dispenser zit.

Conclusie: Test is behaald. De dispenser kan nu soepel de biljetten verwijderen. Hiervan is ook het uitgangspunt beveiligd door een snoep automaat klep als voorbeeld te nemen.

4. Testen voor het ATM behuizing.

Verwachte resultaat: Dat we een behuizing hebben voor onze ATM die aan alles voldoet.

Waarneming: Bij het maken van de ATM zijn we eerst met afmetingen vanuit gegaan van Jurgens laptop. We gebruiken hierbij Jurgens laptop scherm als het scherm van de ATM. Hier baseren wij de werking van de GIU. De afmetingen hebben we in ons GitHub documenten staan via tinkerscad.

Daarna is Wouter via adobe editor de afmetingen van de ATM aan het maken. Hierbij was het dikte van de plank minstens 3mm de rest zijn ook in de documenten te vinden. We hebben uiteindelijk de ATM in 2 delen gesplist. Het was anders echter te groot voor ons. Hiervan is het onderste deel van de dispenser en het bovenste deel de rest van de componenten.

Uiteindelijk is Jia gaan laser cutten. Waarvan we een fout tegen kwamen. Dit waren de bovenste zijkanten van onze ATM. Ze waren echter te klein voor het formaat. Dit moest opnieuw gesneden worden.

De afmetingen staan op tinkercad, die is gelinkt via GitHub. Verder zitten de laser cut afmetingen in de map documenten > ATM laser cut. Hier is het ontwerp van onze ATM in tinkerscad:

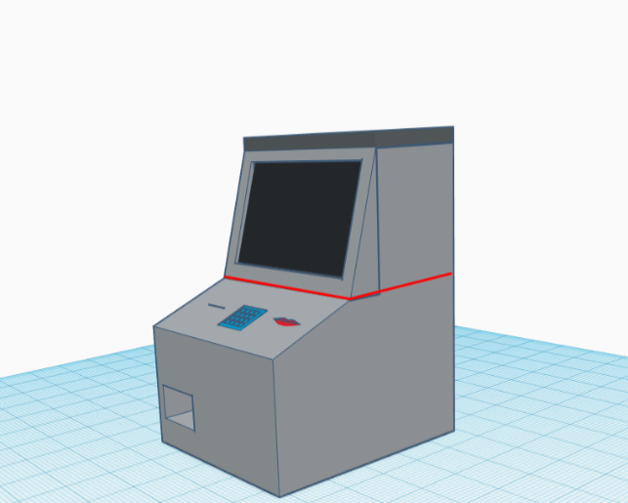
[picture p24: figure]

Conclusie: Test is behaald. Het ATM is eindelijk een complete set geworden, waarvan alle componenten erin zitten.

5. Afhankelijke testen voor de keypad en RIFD

Verwachte resultaat: Testen op defecte componenten en dat er een code gemaakt wordt.

Waarneming: We gingen vooral kijken of er geen defecte keypad of een stappenmotor hadden. Dit deden we door een voorbeeld code op Arduino IDE te pakken.

De code staat in onze GitHub onder code > alles > losse onderdelen > keypaden en RIFD.

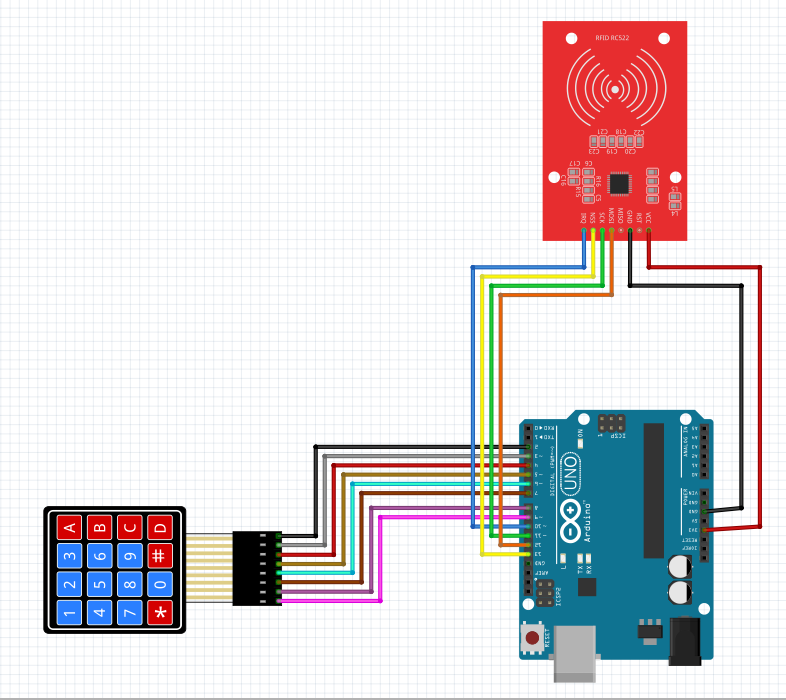
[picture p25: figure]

Uiteindelijk waren de componenten goed. Dus we hoefden geen nieuwe te halen. De werking voor beide componenten waren via Arduino al makkelijk te maken. Dit is dan via de waardes aangepast.

Conclusie: Test is geslaagd. Er waren geen fouten tijdens het verbinden van 2 componenten. Er waren ook geen defecte componenten langs gekomen. Dus een succesvolle test.

6. Testen op veiligheid voor de ATM.

Verwachte resultaat: Zorgen dat onze ATM beveiligd is op aanvallen van een dief.

Waarneming: Voor deze test moesten we onze ATM zo veilig mogelijk maken. Dieven mogen dus niet direct in aanraking komen met onze bron componenten van het systeem. Dus voor het eerste component gaat het om de dispenser. De dief mag niet met zijn hand bij de biljetten komen. We hebben hiervoor een voorbeeld genomen van een snoep automaat. Een snoep automaat kan dus de aanvaller tegen houden om een uitgang klepje toe te voegen. Het is alleen via het opening naar binnen te gaan. Dus voor onze dispenser hebben we een houten klepje toegevoegd.

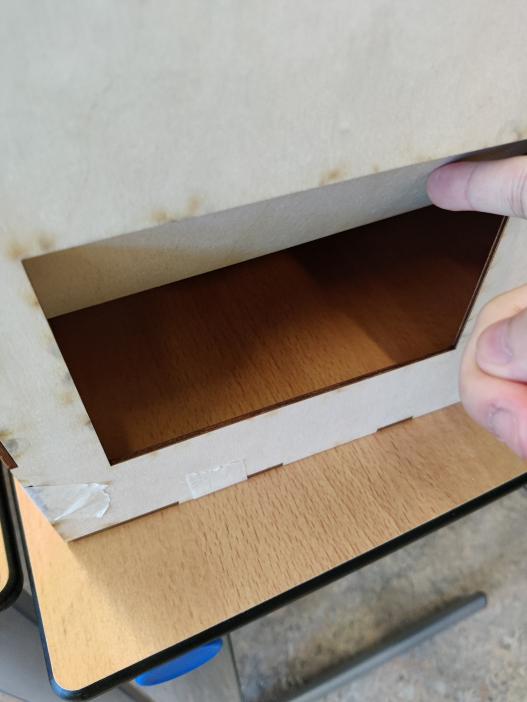
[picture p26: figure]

Daarna zijn alle componenten goed verbonden met elkaar. Er is met kabel management een duidelijk inzicht.

De buitenkant is niet bereikbaar voor de aanvaller. Hier is een proef voorkant foto.


Daarna hebben we nog een robuust video in onze GitHub folders.

Conclusie: De test is behaald. Onze ATM is nu wel veilig tegen de aanvallers. Hierdoor zal de klant veilig kunnen pinnen.

7. Testen op een complete database.

Verwachte resultaat: De database werken op de bank server.

Waarneming: In de eerste week hadden we een test database opgericht. Hiervan hadden we een gratis database op internet gevonden die we konden gebruiken. Om het inhoud te checken staat het op GitHub onder documenten.

Hiervan hadden we een API in elkaar gezet die dan met onze GUI communiceert.

We kunnen dus met de GUI de waardes aanpassen.

De waardes staan op GitHub en we hebben onze foto’s en filmpjes laten zien.


Conclusie: Test is behaald. Er is ook een filmpje in de documenten.

8. Testen om saldo checken.

Verwachte resultaat: Dat de gebruiker zijn saldo kan zien wanneer hij/zij inlogt.

Waarneming: We hadden alles Java gemaakt. Hiervan hebben we de code om de waarde van alles te kunnen zien. Dit is direct verbonden met de server.


Conclusie: Deze test is behaald. De saldo kan gecheckt worden.

9. Testen op een voor pincode.

Verwachte resultaat: Dat de aantal pogingen worden onthouden en geblokkeerd.

Waarneming: In onze code houden we vast hoeveel pogingen er zijn geweest en of het goed is. De rest is verbonden met de database.


Conclusie: De test is behaald. Er is ook een filmpje hiervan.

10. Testen dat de beveiliging van onze GUI.

Verwachte resultaat: De GUI is beveiligd door een SSH en encryptie.

Waarneming: Onze bank weergeeft geen Iban of pincode. Dus dit is beveiligd dat de aanvaller geen zicht heeft op de gebruiker gegevens.

Conclusie: Deze test is behaald en is goed beveiligd.

11. Testen op de API

We kunnen de API testen met een de functies. Bijvoorbeeld wij willen 50 halen en die stuurt een request aan de landserver en we krijgen een get requests. We kunnen dus communiceren met de GUI via de API en kunnen pinnen bij andere banken.


Output van onze console er werd een get request terug gekregen via de API.

Verwachte resultaat: Wij onze API stuurt de correcte response en krijgen de correcte response.

Waarneming: Er werd een correcte response gekregen via de API en dus de correcte reponse werd gestuurd via onze API.

Conclusie: Deze test is behaald de API werkt correct.

[^1]

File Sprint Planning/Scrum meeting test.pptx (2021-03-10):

## PO Meeting

## Sprint review

- GUI ontwerpen en maken
- Onderzoek gedaan aan de RFID

## Pin pagina – Eerste iteratie


## Start pagina – Eerste iteratie


## Openemen Pagina – Eerste iteratie


## Presentatie Sprint Backlog

Features | Wat | Wie | Waarom | Taken | Moeilijkheids-graad | Acceptance criteria
1 | Je pas kunnen scannen. | De opdrachtgever | Zodat het systeem jouw identiteit en saldo kan checken. | Fritzing maken van de RFID | 4 | Een signaal terug kunnen krijgen van het pasje.
| | | | Ontwerp voor pashouder. | | Zonder pas geen toegang tot het systeem.
| | | | RFID moet de pas kunnen detecteren.
2 | Een algemene GUI. | De opdrachtgever | Om de transacties te bekijken. | Onderzoek naar GUI in Java. | 10 | Een voor pagina moet een logo, taal knop en een hulp gif bevatten.
| | | | Een lay-out maken. | | Menu bevatten.
| | | | Coderen van de GUI.
3 | Je pincode in kunnen voeren. | De opdrachtgever | Om veilig te kunnen pinnen. | Fritzing maken van de numpad. | 3 | De pincode moet gevraagd worden en opgenomen.
| | | | Een array test opstellen, om codes op te slaan van de numpad.

## Retrospective

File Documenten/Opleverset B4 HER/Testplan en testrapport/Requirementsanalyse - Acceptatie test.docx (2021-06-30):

# Requirementsanalyse - Acceptatie test

Project ¾

Groep : Bryan Chung (0990458), Jia-jie Yeh (0992427), Jurgen van den Berg (1000875) en Wouter van Huut (1018984).


# Requirements

| Functies
F1 | Gelddispenser (minstens twee geldlades) | Must
F2 | Kunnen pinnen bij eigen automaat gebruikmakend van RFID | Must
F3 | Pincode invoeren om in te loggen | Must
F4 | Beveiligingsplan over de beveiliging van de bank | Must
F5 | Saldo checken in de GUI | Must
F6 | Optie printen bon in GUI | Must
F7 | Bon printen na transactie | Must
F8 | Het pinproces moet altijd afgebroken kunnen worden | Must
F9 | De gebruiker moet altijd terug kunnen keren naar het hoofdmenu | Must
F10 | Melding als er te weinig saldo is | Must
F11 | Bij onvoldoende saldo kan de gebruiker niet pinnen | Must
F12 | Onthouden aantal pogingen intoetsen pincode | Must
F13 | Na 3 foute pincodes pas blokkeren | Must
F14 | Na correcte pincode aantal foutpogingen resetten | Must
F15 | Snel keuze maken welke biljetten je wilt pinnen(snel 70 euro pinnen) | Must
F16 | Keuze maken welke biljetten je wilt pinnen | Must
F17 | Alleen biljetopties geven die mogelijk zijn | Must
F18 | Kunnen pinnen bij andere banken binnen jouw land | Must
F19 | Kunnen pinnen bij andere banken in ander land | Must
F20 | Zelf een bedrag kunnen intoetsten | Must
F21 | Verschillende talen kiezen | Should
F22 | Online bankieren | Should

# Inloggen

Acceptatie test: | F2, F3 en F8
Test: | De gebruiker kan inloggen, maar ook snel afbreken.
Criteria: | De gebruiker moet inloggen en uitloggen.
Test opstelling: | De gebruiker maakt gebruik van de GUI en gaat daarmee inloggen.
Test procedure: | - De gebruiker laat zijn pas scannen met de RFID. - De gebruiker moet zijn pincode invoeren door middel van de numpad. - De gebruiker kan zijn proces afbreken door middel met zijn pas uit te halen.
Test resultaat: | De gebruiker kan met de ingebouwde gleuf zijn pas erin laten en inloggen met zijn gegeven pincode. Om alles af te breken kan de gebruiker via de GUI navigeren. Of maakt gebruik van zijn pas om meteen uit te loggen.
Test geslaagd: | De test is behaald.

# Pin proces

Acceptatie test: | F1, F6, F7, F16, F17 en F20
Test: | De werking van biljet pinnen.
Criteria: | Als er wordt gepind, moeten de biljetten vloeiend uitkomen.
Test opstelling: | De gebruiker maakt gebruik van de GUI, door biljetten te kiezen en opties te krijgen. Daarna moet het signaal doorgeven aan de dispenser en bon printer.
Test procedure: | - De gebruiker voert een gewenste bedrag in. - Of de gebruiker wilt het biljet die hij zelf invoert. - Ook keuze uit bon of niet. - Door het doorgeven van de biljet wordt er doormiddel van gebruikt gemaakt van de dispenser. We hebben hier 3 laatjes van. Dus 10, 20 en 50 euro. Als de gewenste bedrag is in gevoerd gaat het van groot naar klein uitgeprint worden. - Wanneer het dispenser proces is verwerkt krijgt u uw bon.
Test resultaat: | De gebruiker krijgt zijn gewenste biljetten met de bon erbij.
Test geslaagd: | De test is behaald.

# GUI & Navigatie

Acceptatie test: | F3, F5, F8, F9, F15, F16, F17, F20, F21
Test: | De werking van de GUI en hoe je het moet navigeren.
Criteria: | De GUI moet de juiste opties aantonen en moet genavigeerd worden met de numpad.
Test opstelling: | De GUI draait op een laptop Java programma. De opties zijn in de GUI weergeven. En het wordt genavigeerd met een numpad.

Test procedure:

- De gebruiker logt in via zijn pincode
- Als de gebruiker inlogt kan hij/zij zijn saldo zien.
- Na het inloggen is de numpad de navigatie systeem. Dus ze kunnen door de toetsen op de numpad de opties bereiken. Ook is het zo dat de toets namen op de opties staan.
- De gebruiker kan zijn pin proces afbreken door middel van zijn pas uit te steken of terug gaan knop.
- De gebruiker kan terug gaan naar de hoofd menu door middel van de terug gaan knop.
- Er is ook een snel optie om 70 euro te gaan pinnen.
- De gebruiker kan kiezen wat hij voor biljetten hij pint en de opties er voor geven.
- De gebruiker kan zelf een bedrag invullen. Doormiddel van de numpad.
- In de hoofdmenu kan de gebruiker de taal aanpassen naar Engels.

Test resultaat: | De gebruiker kan door de GUI heen gaan zonder problemen.
Test geslaagd: | De test is behaald.

# Saldo check

Acceptatie test: | F10 en F11
Test: | Wanneer de gebruiker pint op onvoldoende saldo wordt dit geweigerd.
Criteria: | Zorgen dat de gebruiker niet kan pinnen en een waarschuwing krijgt wanneer er te weinig saldo is.
Test opstelling: | De test wordt op de Java GUI programma gedaan. Hiervan moet je een pas hebben op in te loggen en je saldo te checken. En daarna te kunnen pinnen.
Test procedure: | - Op elke pas is een eigen account en hiervan dus eigen saldo. - Om te checken moet je eerst inloggen. - Als er te weinig saldo is dan zie je dat op je scherm na het inloggen. - Als je pint op onvoldoende saldo lukt het niet.
Test resultaat: | De gebruiker kan zijn saldo checken en kan met onvoldoende saldo niet pinnen.
Test geslaagd: | De test is behaald.

# Pas blokkeren

Acceptatie test: | F3 en F13
Test: | De gebruiker kan na 3 keer mislopen niet meer inloggen.
Criteria: | Als de gebruiker meer dan 3 keer de verkeerde wachtwoord invoert dan wordt de pas geblokkeerd. Maar als het bij de 2e keer mis gaat, maar 3e keer goed dan is het ‘gerefreshed’.
Test opstelling: | Er wordt gebruik gemaakt van de numpad en de pas RFID scanner. En de GUI.
Test procedure: | - Eerst wordt de pas gescand via de RFID - Daarna wordt het getest op de 2 keer blokkeren. Dan refreshen. Dus alle pogen zijn er weer. - Nu na 3 keer mislopen van het invoeren kan de gebruiker niet meer inloggen.
Test resultaat: | De gebruiker kan niet meer inloggen met zijn pas.
Test geslaagd: | De test is behaald.

# Bon printer

Acceptatie test: | F6, F7 en F21
Test: | De bon kan geprint worden en taal erop kan veranderd worden.
Criteria: | De bon moet geprint worden op keuze van de gebruiker en de taal kan veranderd zijn volgens de gebruiker.
Test opstelling: | Er wordt gebruikt gemaakt van de GUI Java programma. In het menu scherm is taal keuze en bij het gemaakte bedrag keuze kom de bon eruit naar keuze.
Test procedure: | - Eerst wordt er ingelogd. - Er wordt eerst in het Nederlands getest. - Hiervan gaan we een bedrag invoeren, waarvan we de optie krijgen om de bon te printen. Hierdoor krijgen we de bon eruit in het Nederlands. Dit is hetzelfde geval voor Engels.
Test resultaat: | De gebruiker kan de taal van de bon veranderen. En heeft keuze uit of de bon geprint wordt of niet.
Test geslaagd: | De test is behaald.

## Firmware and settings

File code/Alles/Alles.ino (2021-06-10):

/*---------------
commands in: 
  - dispense:<aantal 50>,<aantal 20>,<aantal 10>  --- geef aan dat de machine geld moet uitwerpen en welke hoeveelheden van de verschillende briefjes
  - printBon:<aantal gepind>,<aantal genoneerd>   --- geef aan dat de machine een bon moet printen en welke hoeveelheden er op moeten staan
commands uit:
  - key:<toets uit keypad>      --- geeft aan dat er een toets is aangeslagen en geeft dit door
  - uid:<key van rfid kaart>    --- geeft aan dat er een uid is gelezen en geeft dit door
  - "removed card"              --- geeft aan dat een kaart is verwijderd
  - "done with boot"            --- geeft aan dat het geboot is, doet de gui niks mee, naast dat het herkent dat het een seriele input heef ontvangen
  - geldUitgeworopen:<aantal 50>,<aantal 20>,<aantal 10>  --- geeft aan dat de machine klaar is met het uitwerpen van geld en de hoeveelheden hiervan
--------------*/

#include <SPI.h>
#include <MFRC522.h>
#include <Keypad.h>
#include "Adafruit_Thermal.h"
#include "SoftwareSerial.h"
#include <Stepper.h>
#define TX_PIN 37 // BLAUWE WIRE   RX op printer
#define RX_PIN 39 // GROENE WIRE   TX op printer
#define SS_PIN 53 // RFID
#define RST_PIN 5 // RFID
#define ROW_NUM 4
#define COLUMN_NUM 4

//Keypad
char keys[ROW_NUM][COLUMN_NUM] = {
  {'1','2','3', 'A'},
  {'4','5','6', 'B'},
  {'7','8','9', 'C'},
  {'*','0','#', 'D'}
};
byte pin_rows[ROW_NUM] = {42, 44, 46 , 48};
byte pin_column[COLUMN_NUM] = {43, 45, 47, 49};

// RFID
byte nuidPICC[4];
int count = 3;
bool newCard = true;

MFRC522 rfid(SS_PIN, RST_PIN);
MFRC522::MIFARE_Key key;

Keypad keypad = Keypad(makeKeymap(keys), pin_rows, pin_column, ROW_NUM, COLUMN_NUM);

// Motoren
const int stepsPerRevolution = 2048;
Stepper myStepper1 = Stepper(stepsPerRevolution, 26, 30, 28, 32); // Maak stepper opject aan | Pin 26 = IN1 | Pin 30 = IN3 | Pin 28 = IN2 | Pin 32 = IN4 |  -------50 eu
Stepper myStepper2 = Stepper(stepsPerRevolution, 34, 38, 36, 40); // Maak stepper opject aan | Pin 34 = IN1 | Pin 38 = IN3 | Pin 36 = IN2 | Pin 40 = IN4 |  -------20 eu
Stepper myStepper3 = Stepper(stepsPerRevolution, 23, 27, 25, 29); // Maak stepper opject aan | Pin 42 = IN1 | Pin 46 = IN3 | Pin 44 = IN2 | Pin 48 = IN4 |  -------10 eu

//Themal Pinter
SoftwareSerial mySerial(RX_PIN, TX_PIN); // Declare SoftwareSerial obj first
Adafruit_Thermal printer(&mySerial);     // Pass addr to printer constructor


void setup(){
  Serial.begin(9600);
  // Zet de snelheden voor de motoren in rpm
  myStepper1.setSpeed(15);
  myStepper2.setSpeed(15);
  myStepper3.setSpeed(15);
  SPI.begin();
  rfid.PCD_Init();
  Serial.println("done with boot");
}



void loop() {
  handleSerial();
  handleCard();
  handleKey();
}

void bonprint(int pinaantal, String Time) {
  int totaalpin = pinaantal;

  mySerial.begin(9600);  // Begin resial voor printer
  printer.begin();        // Begin printer


  // Print logo bovenaan
  printer.justify('C');
  printer.boldOn();
  printer.setSize('L');
  printer.print(F("Fake"));
  printer.boldOff();

  printer.boldOn();
  printer.inverseOn();
  printer.setSize('L');
  printer.println(F("ATM"));
  printer.boldOff();
  printer.inverseOff();
  // ----------------------------------

  // Print pin amount
  printer.setLineHeight(64);
  printer.justify('L');
  printer.setSize('S');
  printer.print(F("Aantal gepind               "));
  printer.boldOn();
  printer.setSize('S');
  printer.println(pinaantal);
  printer.boldOff();
  // ----------------------------------

  // Print donatie aantal
  // printer.setLineHeight(32);
  // printer.justify('L');
  // printer.setSize('S');
  // printer.print(F("Donatie                     "));
  // printer.boldOn();
  // printer.setSize('S');
  // printer.println(donatieaantal);
  // printer.boldOff();
  // ----------------------------------

  // Print totaal aantal
  printer.setLineHeight(64);
  printer.justify('L');
  printer.setSize('S');
  printer.print(F("Totaal                      "));
  printer.boldOn();
  printer.setSize('S');
  printer.println(totaalpin);
  printer.boldOff();
  // ----------------------------------

  /* 
  Tijd printen
  printer.setLineHeight(256);
  printer.justify('C');
  printer.setSize('S');
  printer.print(day());
  printer.print("|");
  printer.print(month());
  printer.print("|");
  printer.println(year());
  */
  // ----------------------------------

  // Locatie printen
  printer.setLineHeight(48);
  printer.justify('C');
  printer.setSize('S');
  printer.println("fakeATM - Niger");
  // ----------------------------------

  printer.setLineHeight(32);
  printer.justify('C');
  printer.setSize('S');
  printer.println(Time);

  // laat wat plek onderaan zodat de bon makkelijk uitneembaar is zonder dat er worden vergaan
   printer.setLineHeight(256);
   printer.setLineHeight(50);
   printer.println(F(""));
   printer.println(F(""));
   printer.println(F(""));
  // ----------------------------------

  // Reset de printer
  printer.sleep();      
  //  delay(5);         
  printer.wake();       
  printer.setDefault(); 
  // ----------------------------------

  Serial.print("bonGeprint:");
  Serial.print(pinaantal);
  Serial.print(",");
  Serial.print(Time);
  Serial.println(" ");
}
void motordraai(int motornr){
  if (motornr == 1) {
    myStepper1.step(stepsPerRevolution);
    digitalWrite(26, LOW);
    digitalWrite(28, LOW);
    digitalWrite(30, LOW);
    digitalWrite(32, LOW);
  }
  else if (motornr == 2) {
    myStepper2.step(stepsPerRevolution);
    digitalWrite(34, LOW);
    digitalWrite(36, LOW);
    digitalWrite(38, LOW);
    digitalWrite(40, LOW);
  }
  else {
    myStepper3.step(stepsPerRevolution);
    digitalWrite(23, LOW);
    digitalWrite(25, LOW);
    digitalWrite(27, LOW);
    digitalWrite(29, LOW);
  }
}
void handleSerial() {
  while(Serial.available() > 0) {
    String recieved = Serial.readStringUntil(':');
    if(recieved == "dispense") {
      int aantal50 = Serial.readStringUntil(',').toInt();
      int aantal20 = Serial.readStringUntil(',').toInt();
      int aantal10 = Serial.readStringUntil(',').toInt();
      werpGeldUit(aantal50, aantal20, aantal10);
    } else if(recieved = "printBon") {
      int geldAantal = Serial.readStringUntil(',').toInt();
      String Time = Serial.readStringUntil(',');
      Serial.print("aantal gepind: ");
      Serial.println(geldAantal);
      Serial.print("aantal gedoneerd: ");
      Serial.println(Time);
      bonprint(geldAantal, Time);
    }
  }
}

void handleCard() {
  bool readCard = rfid.PICC_ReadCardSerial();
  bool trash = rfid.PICC_IsNewCardPresent();
  
  if(readCard) {
    if(newCard) {
      printUid();
      newCard = false;
      delay(1000);
    }
    count = 0;
  } else {
    count++;
    if(count == 2) {
      newCard = true;
      Serial.println("removed_card ");
      delay(1000);
    } else if(count > 2) {
      count = 3;
    }
  }
}

void handleKey() {
  char key = keypad.getKey();
  if(key) {
    Serial.print("key: ");
    Serial.print(key);
    Serial.println(" ");
  }
}

void werpGeldUit(int aantal50, int aantal20, int aantal10) {
  for(int i = 0; i < aantal50; i++) {
    Serial.println("briefje van 50 aan het printen.....");
    motordraai(1);
  }
  delay(500);
  for(int i = 0; i < aantal20; i++) {
    Serial.println("briefje van 20 aan het printen.....");
    motordraai(2);
  }
  delay(500);
  for(int i = 0; i < aantal10; i++) {
    Serial.println("briefje van 10 aan het printen.....");
    motordraai(3);
  }

  Serial.print("geldUitgeworpen:");
  Serial.print(aantal50);
  Serial.print(",");
  Serial.print(aantal20);
  Serial.print(",");
  Serial.print(aantal10);
  Serial.println(" ");
}

void printUid() {
  //  MFRC522::PICC_Type piccType = rfid.PICC_GetType(rfid.uid.sak);
  //  if (piccType != MFRC522::PICC_TYPE_MIFARE_MINI &&  
  //    piccType != MFRC522::PICC_TYPE_MIFARE_1K &&
  //    piccType != MFRC522::PICC_TYPE_MIFARE_4K) {
  //    //Serial.println(F("Your tag is not of type MIFARE Classic."));
  //    return;
  //  }

  // Store NUID into nuidPICC array
  for (byte i = 0; i < 4; i++) {
    nuidPICC[i] = rfid.uid.uidByte[i];
  }

  Serial.print("uid:");
  for (byte i = 0; i < rfid.uid.size; i++) {
    Serial.print(rfid.uid.uidByte[i] < 0x10 ? " 0" : " ");
    Serial.print(rfid.uid.uidByte[i], HEX);
  }
  Serial.println(" ");
  
  // Halt PICC
  rfid.PICC_HaltA();

  // Stop encryption on PCD
  rfid.PCD_StopCrypto1();
}

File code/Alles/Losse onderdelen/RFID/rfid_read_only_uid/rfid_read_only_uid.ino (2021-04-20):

/*
 * --------------------------------------------------------------------------------------------------------------------
 * Example sketch/program showing how to read new NUID from a PICC to serial.
 * --------------------------------------------------------------------------------------------------------------------
 * This is a MFRC522 library example; for further details and other examples see: https://github.com/miguelbalboa/rfid
 * 
 * Example sketch/program showing how to the read data from a PICC (that is: a RFID Tag or Card) using a MFRC522 based RFID
 * Reader on the Arduino SPI interface.
 * 
 * When the Arduino and the MFRC522 module are connected (see the pin layout below), load this sketch into Arduino IDE
 * then verify/compile and upload it. To see the output: use Tools, Serial Monitor of the IDE (hit Ctrl+Shft+M). When
 * you present a PICC (that is: a RFID Tag or Card) at reading distance of the MFRC522 Reader/PCD, the serial output
 * will show the type, and the NUID if a new card has been detected. Note: you may see "Timeout in communication" messages
 * when removing the PICC from reading distance too early.
 * 
 * @license Released into the public domain.
 * 
 * Typical pin layout used:
 * -----------------------------------------------------------------------------------------
 *             MFRC522      Arduino       Arduino   Arduino    Arduino          Arduino
 *             Reader/PCD   Uno/101       Mega      Nano v3    Leonardo/Micro   Pro Micro
 * Signal      Pin          Pin           Pin       Pin        Pin              Pin
 * -----------------------------------------------------------------------------------------
 * RST/Reset   RST          9             5         D9         RESET/ICSP-5     RST
 * SPI SS      SDA(SS)      10            53        D10        10               10
 * SPI MOSI    MOSI         11 / ICSP-4   51        D11        ICSP-4           16
 * SPI MISO    MISO         12 / ICSP-1   50        D12        ICSP-1           14
 * SPI SCK     SCK          13 / ICSP-3   52        D13        ICSP-3           15
 */

#include <SPI.h>
#include <MFRC522.h>

#define SS_PIN 10
#define RST_PIN 9
 
MFRC522 rfid(SS_PIN, RST_PIN); // Instance of the class

MFRC522::MIFARE_Key key; 

// Init array that will store new NUID 
byte nuidPICC[4];

void setup() { 
  Serial.begin(9600);
  SPI.begin(); // Init SPI bus
  rfid.PCD_Init(); // Init MFRC522 

  for (byte i = 0; i < 6; i++) {
    key.keyByte[i] = 0xFF;
  }

//  Serial.println(F("This code scan the MIFARE Classsic NUID."));
//  Serial.print(F("Using the following key:"));
//  printHex(key.keyByte, MFRC522::MF_KEY_SIZE);
}
 
void loop() {

  // Reset the loop if no new card present on the sensor/reader. This saves the entire process when idle.
  if ( ! rfid.PICC_IsNewCardPresent())
    return;

  // Verify if the NUID has been readed
  if ( ! rfid.PICC_ReadCardSerial())
    return;

  //Serial.print(F("PICC type: "));
  MFRC522::PICC_Type piccType = rfid.PICC_GetType(rfid.uid.sak);
  //Serial.println(rfid.PICC_GetTypeName(piccType));

  // Check is the PICC of Classic MIFARE type
  if (piccType != MFRC522::PICC_TYPE_MIFARE_MINI &&  
    piccType != MFRC522::PICC_TYPE_MIFARE_1K &&
    piccType != MFRC522::PICC_TYPE_MIFARE_4K) {
    //Serial.println(F("Your tag is not of type MIFARE Classic."));
    return;
  }


    // Store NUID into nuidPICC array
    for (byte i = 0; i < 4; i++) {
      nuidPICC[i] = rfid.uid.uidByte[i];
    }
   
    //Serial.println(F("The NUID tag is:"));
    //Serial.print(F("In hex: "));
    //printHex(rfid.uid.uidByte, rfid.uid.size);
    //Serial.println();
    //Serial.print(F("In dec: "));
    Serial.print("key: ");
    printDec(rfid.uid.uidByte, rfid.uid.size);
    Serial.println();

  // Halt PICC
  rfid.PICC_HaltA();

  // Stop encryption on PCD
  rfid.PCD_StopCrypto1();
}


/**
 * Helper routine to dump a byte array as hex values to Serial. 
 */
void printHex(byte *buffer, byte bufferSize) {
  for (byte i = 0; i < bufferSize; i++) {
    Serial.print(buffer[i] < 0x10 ? " 0" : " ");
    Serial.print(buffer[i], HEX);
  }
}

/**
 * Helper routine to dump a byte array as dec values to Serial.
 */
void printDec(byte *buffer, byte bufferSize) {
  for (byte i = 0; i < bufferSize; i++) {
    Serial.print(buffer[i] < 0x10 ? " 0" : " ");
    Serial.print(buffer[i], DEC);
  }
}

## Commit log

2021-03-04 Pagina Pin Pad
2021-03-04 Frames toegepast aan de pinpad pagina
2021-03-09 Powerpoint toegevoegd
2021-03-10 Powerpoint gemaakt
2021-03-10 Powerpoint aangepast
2021-03-11 meerdere dingen aangepast
    [Keypad.fzz]
2021-03-11 rfid in code map gedaan
    [RFID.fzz]
2021-04-20 code arduino aangepast
2021-04-21 Fritzing Keypad en RFID samen
    [KeypadenRFID.fzz]
2021-04-21 Motor aandrijving
2021-04-21 Fritzing Motor
    [Motor.fzz]
2021-04-23 code arduino voor mega toegevoegd
2021-04-28 RFID en Keypad toegevoegd aan de Alles.ino
2021-04-29 uitkomsten form bijgevoegd
    [kleurkeuzes uitkomsten form.xlsx]
2021-04-29 pin veranderingen
2021-04-29 nog een dia
2021-04-29 Complete ino afgemaakt en de files beter gesoorteerd
    [Alles.fzz, Keypad.fzz, KeypadenRFID.fzz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]
2021-04-29 serieel doet het?
2021-05-17 gereed actie string toegevoegd in de variables class
2021-05-19 nieuw flowchart gemaakt
2021-05-27 talen toegevoegd bij als het goed is alles in de gui
2021-05-31 queries voor de database
2021-06-10 reflectie verslag
    [Alles.fzz]
